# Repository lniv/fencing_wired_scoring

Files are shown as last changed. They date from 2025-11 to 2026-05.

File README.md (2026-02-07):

# A simple fencing scoring system

The aim is to make it simple, rather than efficient or super precise.\
Towards that, the hardware is a LED display with a matching controller from adafruit,
and circuitpython is used vs e.g. C. I tried to keep hardware to minimum, but pullup resisotrs appear necesssary for wired operation.

Note: foil only currently.

## Setup

### Display

#### Common to wired and wireless setups

These instructions assume a matrixportal-S3 is used as the display controller. There is nothing magical about it, but it is convenient.

- Install circuitpython on the matrixportal S3 : https://learn.adafruit.com/adafruit-matrixportal-s3/install-circuitpython
- Prep the portal and led display : https://learn.adafruit.com/adafruit-matrixportal-s3/prep-the-matrixportal
- Wire a buzzer between the A0 (battery connector) and ground.
- Copy [code.py](./code.py), [settings.toml](./settings.toml) and the various bmp files onto the circuitpython drive.

#### Additional display / connector setup for wired use:

I added the wireless option later, so e.g. the display legs or buzzer holder were integrated with parts that are necessary only for wired operation.

- Solder 2.2kohm (or similar) pullup resistors between the two weapon lines and 3V on the matriportalS3. These may not be necessary if you're using a different controller, in which case you should disable the pullup option ("HAVE_EXTERNAL_PULLUPS") in the settings.toml file.
- Print [display_connector.step](hardware/display_connector.step) and 2 or 3 of [display_leg](hardware/display_leg.step), and use a few M3x12 screws attach to display.
- Install and wire the six banana jacks.

### Wireless setups
- The two fencer boxes are described [here](./fencer_boxes/README.md).
- The display will create an AP with the ssid/password defined in the toml file - the default is ok for a single box.
- The three boxes can be powered on at any order, but if a fencer box doesn't find the AP, it will wait 5 sec before retrying, so if powered first you may have a 10 sec delay before hits can be registered.

## Usage
- Power display (and fencer boxes if used) via usb (typc-c, micro) connectors. The display likely needs ~ 10W.
- The display will setup up an AP (and operated in wireless mode) if the configuration file is deemed valid for wireless operation.
    - This can be overridden by holding the down button at startup.
- Audio can be enabled / disabled by holding the down button while a tip is pressed.
- Fence.

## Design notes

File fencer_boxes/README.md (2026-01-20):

# Fencer boxes used for a wireless setup

Obviously you'd need two of these. Oveall, they're a combination of a picow (RP2040 based) or pico2w (RP2350 based) with a custom front end.

## Hardware setup
* make a front end (duh). The schematics and layout for the front end are in [here](./front_end).
    * The front end is not tightly tied to the pico(2) pinout, though the code is. The current design uses a TSSOP opamp, which is a bit challenging to solder manually, but the other components were kept to 0805 mostly. The setup is simple enough that it could be built on a generic TSSOP adapter, but at 1$/board throush oshpark, why bother.
    * Wiring for a pico-w/pico2-w:
        * 8 pin header:
            * 1 : Not connected
            * 2 : ground
            * 3 : 3.3V
            * 4 : GP9 (tip sense line)
            * 5 : Not connected
            * 6 : GP10 (tip pullup line)
            * 7 : GP13 (lame drive)
            * 8 : GP26/A0 (lame sense)
        * 3 pin header:
            * 1 : A (lame)
            * 2 : B (weapon / tip)
            * 3 : C (ground / common)
* I typically CA glue them to the pico and wire the connections.
* Have a mechanical setup with the three banana jacks, wired to the front end
* power is via the micro usb connector - I use a small usb battery pack.

## Software setup
* Install circuitpython onto the board; for a pico2w, [https://circuitpython.org/board/raspberry_pi_pico2_w/]
* copy [code.py](./code.py) onto the board
* copy the [settings.toml from the parent folder](../settings.toml) file onto the board AND modify it to select either "left" or "right" side.

## TODO:
* Add step files for suitable hardware boxes
* Add BOM
* Replace opamp with a soic part.

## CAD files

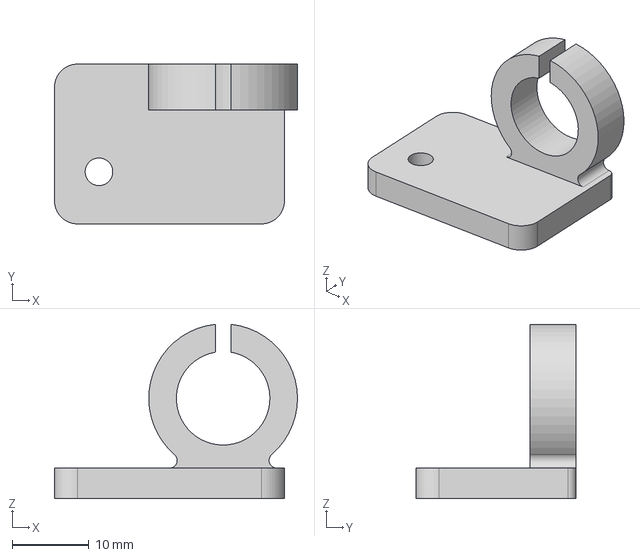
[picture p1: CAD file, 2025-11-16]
hardware/buzzer_holder.step
31.7 x 20.9 x 22.8 mm

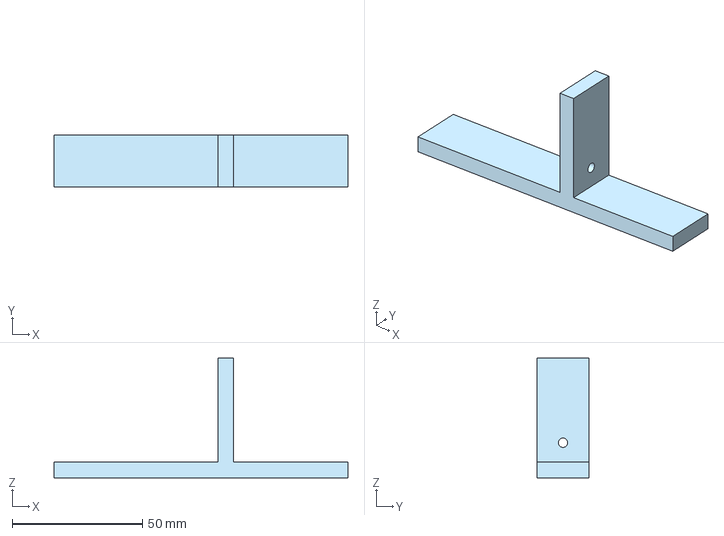
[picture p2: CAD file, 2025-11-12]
hardware/display_leg.step
113.0 x 20.0 x 46.0 mm

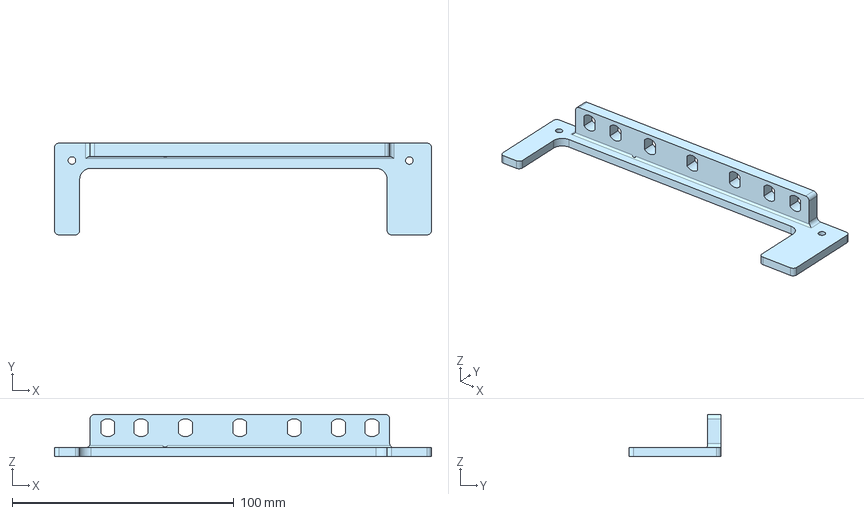
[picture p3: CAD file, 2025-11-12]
hardware/display_connector.step
169.9 x 41.3 x 19.0 mm

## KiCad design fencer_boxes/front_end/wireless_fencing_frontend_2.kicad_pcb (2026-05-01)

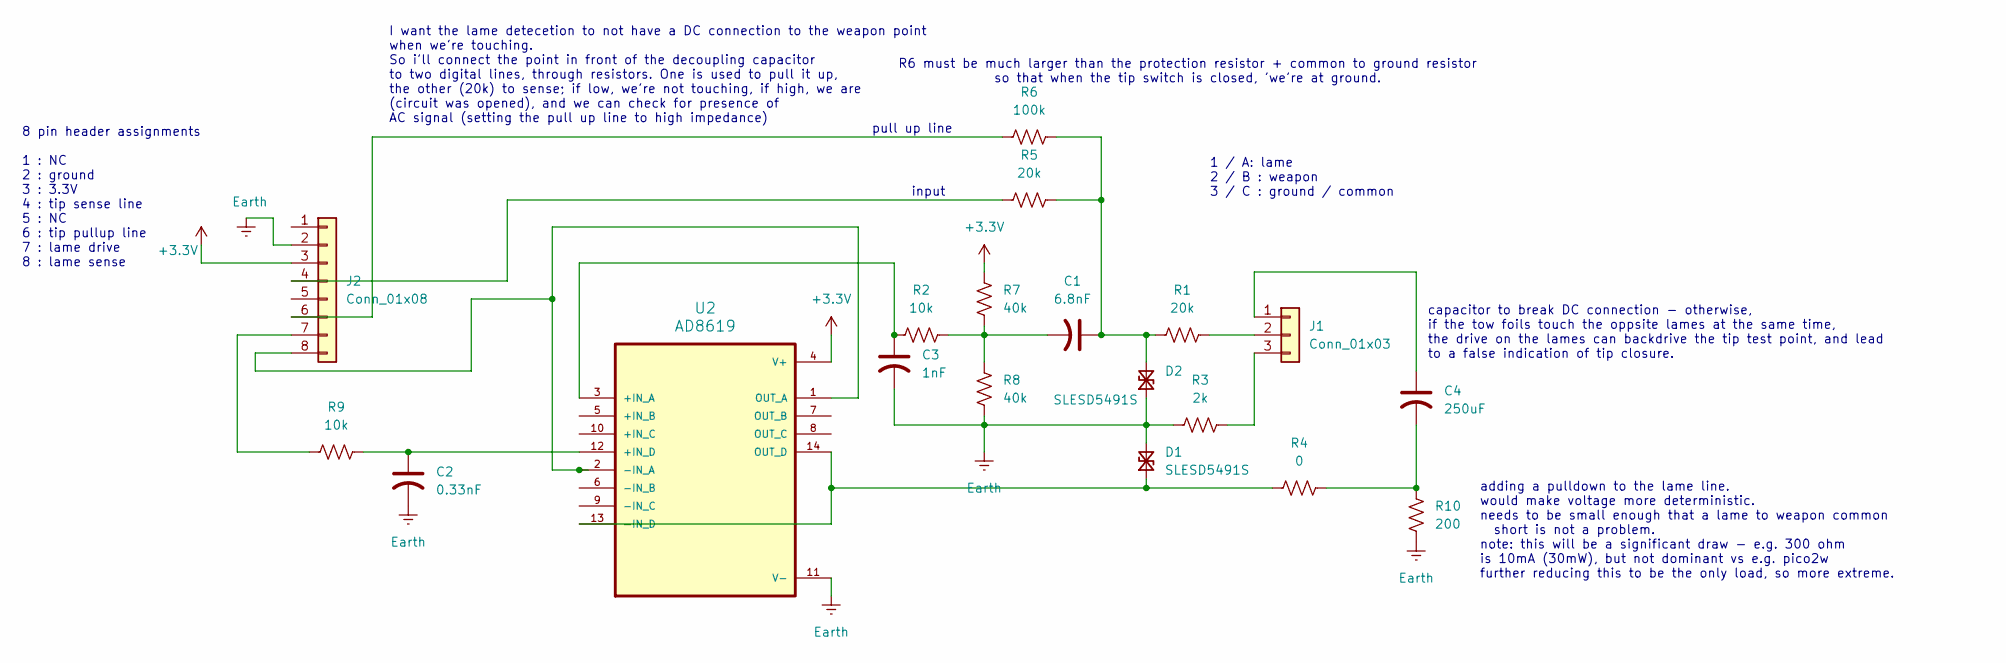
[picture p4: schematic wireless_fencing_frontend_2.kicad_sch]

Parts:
C1: 6.8nF; C_0805_2012Metric
C2: 0.33nF; C_0805_2012Metric
C3: 1nF; C_0805_2012Metric
C4: 250uF; C_0805_2012Metric
D1, D2: SLESD5491S; D_SOD-523
J1: Conn_01x03; PinHeader_1x03_P2.54mm_Vertical
J2: Conn_01x08; PinHeader_1x08_P2.54mm_Vertical
R1, R5: 20k; R_0805_2012Metric
R2, R9: 10k; R_0805_2012Metric
R3: 2k; R_0805_2012Metric
R4: 0; R_0805_2012Metric
R6: 100k; R_0805_2012Metric
R7, R8: 40k; R_0805_2012Metric
R10: 200; R_0805_2012Metric
U2: AD8619; SOP65P640X120-14N

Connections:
+3.3V: J2.3, R7.2, U2.4 (V+)
Earth: C2.2, C3.2, D1.2 (A2), D2.1 (A1), J2.2, R3.1, R8.1, R10.1, U2.11 (V-)
unnamed: C1.2, R2.1, R7.1, R8.2
unnamed: C4.2, R4.2, R10.2
unnamed: D1.1 (A1), R4.1, U2.13 (-IN_D), U2.14 (OUT_D)
unnamed: C1.1, D2.2 (A2), R1.1, R5.2, R6.1
unnamed: C4.1, J1.1
unnamed: J1.2, R1.2
unnamed: J1.3, R3.2
unnamed: J2.4, R5.1
unnamed: J2.6, R6.2
unnamed: J2.7, R9.1
unnamed: J2.8, U2.1 (OUT_A), U2.2 (-IN_A)
unnamed: C3.1, R2.2, U2.3 (+IN_A)
unnamed: C2.1, R9.2, U2.12 (+IN_D)

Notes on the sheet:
input
8 pin header assignments 1 : NC 2 : ground 3 : 3.3V 4 : tip sense line 5 : NC 6 : tip pullup line 7 : lame drive 8 : lame sense
R6 must be much larger than the protection resistor + common to ground resistor so that when the tip switch is closed, 'we're at ground.
pull up line
adding a pulldown to the lame line. would make voltage more deterministic. needs to be small enough that a lame to weapon common short is not a problem. note: this will be a significant draw - e.g. 300 ohm is 10mA (30mW), but not dominant vs e.g. pico2w further reducing this to be the only load, so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
capacitor to break DC connection - otherwise, if the tow foils touch the oppsite lames at the same time, the drive on the lames can backdrive the tip test point, and lead to a false indication of tip closure.
I want the lame detecetion to not have a DC connection to the weapon point when we're touching. So i'll connect the point in front of the decoupling capacitor to two digital lines, through resistors. One is used to pull it up, the other (20k) to sense; if low, we're not touching, if high, we are (c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
1 / A: lame 2 / B : weapon 3 / C : ground / common

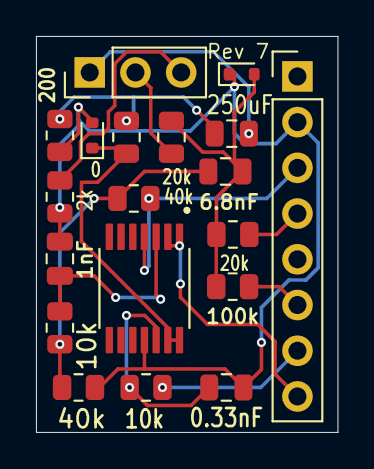
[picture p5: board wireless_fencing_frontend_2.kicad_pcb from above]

Board: 2 copper layers, 16.8 x 22.0 mm, 19 parts (0 on the bottom side), 15 nets.

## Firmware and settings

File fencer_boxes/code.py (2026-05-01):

"""
Code for a wireless fencer box.

need to be able to detect a switch closing, and whether we sense an AC signal (on the opponents lame), sending the results to a server/display.

Since we need the settings.toml for wireless, we'll use it as a general storage.
it will have multiple sections:
1. defines network ssid / password
2. defines which side we're on - you need to edit this, either right or left
3. has common items - e.g. the frequencies used on the lames, detection thresholds, lockout times...

while i could split the settings to multiple files, i decided i preferred a single file with sections.

NOTE: this was used originally with a pico2W i.e. a RP2350:
this required working around errata E9 - the pin latches up without an external
pulldown smaller than 8.2K !!
since the series protection resistor (which ground the pin through the tip) is 20k,
i chose to ground the pin in firmware instead.
"""

import board
from digitalio import DigitalInOut
import time
import analogbufio
import array
import math
import pwmio
import random

import wifi
import socketpool
from os import getenv
from ulab import numpy as np
from ulab.utils import from_uint16_buffer, spectrogram


# standardize on using monotonic_ns as integer, and have times in millisec.

print("Reading from settings.toml")
# before we do anything else, lets see that we have a sane definitions file.
# i could set loops etc here, but keeping names explicit makes the IDE's life easier.
settings = {}
for name in (
    "wifi_ssid",
    "wifi_password",
    "display_ip",
    "display_port",
    "fencer",
    "sampling_rate_Hz",
    "min_touch_msec",
    "sampling_end_to_min_touch_msec",
    "sampling_time_msec",
    "left_Hz",
    "right_Hz",
    "off_peak_offset_Hz",
    "min_valid_power",
    "send_touch_for_msec",
    "dormant_after_hit_msec",
    "message_repeat_min_msec",
    "message_repeat_max_msec",
):
    settings[name] = getenv(name)
    if settings[name] is None:
        raise RuntimeError(f"{name=} not found in settings.toml")

we_are = settings["fencer"]

# i'm going to optimize things to get a power of 2 adc reads
# since the ulab spectrogram requires it in any case.
sampling_rate = settings["sampling_rate_Hz"]
requested_sampling_time_sec = settings["sampling_time_msec"] * 1e-3
pow2_vec = np.array([2**n for n in range(16)])  # enough to ensure cover.
# NOTE: dropping the median filtering. if we decided to add it again,
# we'll need to add the extra 2*half median here.
array_length = int(
    pow2_vec[np.argmin(abs(pow2_vec - sampling_rate * requested_sampling_time_sec))]
)
sampling_time_sec = array_length / sampling_rate
print(
    f"{requested_sampling_time_sec=}, selecting closest 2**n so that {sampling_time_sec=}, {array_length=}"
)
# now find the best match for frequencies.
requested_right_freq = settings["right_Hz"]
requested_left_freq = settings["left_Hz"]
spectrogram_fs = np.linspace(0, sampling_rate / 2, int(array_length / 2 + 1))
right_freq_i = np.argmin(abs(spectrogram_fs - requested_right_freq))
left_freq_i = np.argmin(abs(spectrogram_fs - requested_left_freq))
# casting these since one will be use for a pwm call that takes an integer.
# it's true that these won't be exact, but 0.5 Hz offset seems acceptable.
right_freq = int(spectrogram_fs[right_freq_i])
left_freq = int(spectrogram_fs[left_freq_i])
print(f"Optimized to match spectrogram frequencies")
print(f"{requested_right_freq=} changed to {right_freq=}, {right_freq_i=}")
print(f"{requested_left_freq=} changed to {left_freq=}, {left_freq_i=}")


if we_are == "right":
    out_freq = right_freq
    target_freq = left_freq
    target_freq_i = left_freq_i
elif we_are == "left":
    out_freq = left_freq
    target_freq = right_freq
    target_freq_i = right_freq_i
else:
    raise RuntimeError(
        f"{settings['fencer']=} but we must be FENCER = RIGHT or FENCER = LEFT in settings.toml"
    )

requested_off_peak_offset = settings["off_peak_offset_Hz"]
# rather than look for best below/above indices, which may be not be exactly opposite,
# calculate an optimum delta
delta_i = np.argmin(abs(spectrogram_fs - requested_off_peak_offset))
below_peak_i = target_freq_i - delta_i
above_peak_i = target_freq_i + delta_i

off_peak_freqs = [spectrogram_fs[below_peak_i], spectrogram_fs[above_peak_i]]
print(
    f"Off peak {requested_off_peak_offset=} changed to {off_peak_freqs=}, {below_peak_i=}, {above_peak_i=}"
)


# we have a few floating point values, that due to the circuitpython toml limitations,
# must be loaded as ints. i might just change ot defining them otherwise...
# (i had more than one value, is swear...)
for name in ("min_valid_power",):
    settings[name] = float(settings[name])
    if settings[name] <= 0:
        raise ValueError(f"{name} must be a positive value.")

target_address = (settings["display_ip"], settings["display_port"])

# i'm using these with sleep later, and would prefer to not convert them each time.
message_repeat_min_sec = settings["message_repeat_min_msec"] / 1000
message_repeat_max_sec = settings["message_repeat_max_msec"] / 1000
dormant_after_hit_sec = settings["dormant_after_hit_msec"] / 1000
send_touch_for_ns = settings["send_touch_for_msec"] * 1e6
print(
    f"{dormant_after_hit_sec=}, {send_touch_for_ns=}, repeating every {message_repeat_min_sec:0.3f} to {message_repeat_max_sec:0.3f} sec"
)

print("settings.toml looks sane; proceeding.")

print(
    f"{we_are=}, output at {out_freq} Hz, looking for {target_freq} Hz, {off_peak_freqs=} Hz"
)

# hardware / pin definitions and setup

# connected to lame, through a lowpass filter, so we can do simple square wave.
# low pass will be at ~ 10kHz, so keep frequencies below that.
Lame_A_pin = board.GP13

# we have a resistor connected between the jack and each
# the pull up must be much larger than the protection resistor,
# since that's part of the line going to ground when the tip switch is closed.
# i.e. it won't "allow" it to be pulled to ground otherwise.
tip_B_pull_up_pin = DigitalInOut(board.GP10)  # 100kOhm
tip_B_sense_pin = DigitalInOut(board.GP9)  # 20 kOhm
# set both to high Z to begin.
# actually, i'm going to just have the pull up active
# (i could probably have omitted it and used the built in, but prefer more control.)
tip_B_pull_up_pin.switch_to_output(value=True)
tip_B_sense_pin.switch_to_input(pull=None)


# set up hardare (do this before betwork setup?)
pwm_out = pwmio.PWMOut(
    Lame_A_pin, duty_cycle=2**15, frequency=out_freq, variable_frequency=False
)
print(f"Playing pwm at {out_freq} on {Lame_A_pin}")


# future / TODO: heartbeat to display / server, get time sync from server?
detection_to_sampling_sec = (
    settings["min_touch_msec"] - settings["sampling_end_to_min_touch_msec"]
) * 1e-3 - sampling_time_sec
print(
    f"Will wait for {detection_to_sampling_sec} before sampling for {sampling_time_sec=}."
)

# # i'm going to run a median filter on the data, and do a linear fit subtraction.
# median_half_span = 2
# data_post_median_filt_indices = list(
#     range(median_half_span, array_length - median_half_span)
# )
# median_filtered_length = array_length - 2 * median_half_span
# t_vec = np.linspace(0, median_filtered_length / sampling_rate, median_filtered_length)
print(f"sampling for {sampling_time_sec=}, {sampling_rate=}, N={array_length}")
adc_read_buffer = array.array("H", [0x0000] * array_length)


########### finished setting up


def connect_to_wifi():
    """
    Low level connection to access point
    """
    ssid = settings["wifi_ssid"]
    passwd = settings["wifi_password"]
    print(f"Connecting to {ssid=}, {passwd=}")
    wifi.radio.connect(ssid, passwd)
    print("Connected to WiFi")


def reset_tip_state(ground_sec=0.001, delay_after_sec=0, repeats=1):
    """
    I'm getting repeat phantom touches, which i suspect are the rp2350 bug.
    the normal check does this momentarily, but we can afford to wait much longer after a touch
    (whether is_tip_depressed should as well, maybe)
    TODO: i should make this dependent on whether the board is an rp2350.
    """
    # work around for RP2350 errata E9 - the pin latches up without an external
    # pulldown smaller than 8.2K !!
    # since pulling it down to ground changes our protection, i'd rather do this.
    for _i in range(repeats):
        tip_B_sense_pin.switch_to_output(value=False)
        if ground_sec > 0:
            time.sleep(ground_sec)
        tip_B_sense_pin.switch_to_input(pull=None)
        if delay_after_sec > 0:
            time.sleep(delay_after_sec)


def is_tip_depressed(ground_sense_sec=0.003):
    """
    foil specific ; if we branch in the future, we'll define this based on weapon.
    NOTE: i've moved out any workaround for RP2350 latchup out of this.
    Args:
        ground_sense_sec: if positive, sleep with tip pulled down for this long [0.003]
    Returns:
        True if tip is found to be depressed/touching (circuit open).
    """
    return tip_B_sense_pin.value  # foil : circuit opens upon touch.


class FencerBox:
    """
    Core class looking for hits and sending messages when anything happens.
    """

    def __init__(self):
        self.sock = None
        self.t0_ns = time.monotonic_ns()
        self.connect_to_server()
        self.send_msg(f"{we_are},Just woke up,0,None,None", time.monotonic_ns())
        self.send_msg(
            f"{we_are},now in business - looking for hits,0,None,None", self.t0_ns, 0
        )
        self.run()

    def connect_to_server(self):
        """
        Connect to the display / server.
        Returns:
            a live socket
        """
        if isinstance(self.sock, socketpool.Socket):
            print("Socket existed, closing it before recreating.")
            self.sock.close()
        self.sock = pool.socket(pool.AF_INET, pool.SOCK_STREAM)
        self.sock.setsockopt(pool.IPPROTO_TCP, pool.TCP_NODELAY, 1)
        # sock.settimeout(1)  # very long, in general we should get something back fast.
        # this doesn't exist apparently?
        # sock.setsockopt(pool.SOL_SOCKET, pool.SO_KEEPALIVE, 1)
        print(f"Connecting to {target_address}")
        self.sock.connect(target_address)
        print("Connected.")

    def send_msg(self, msg: str, t_msg_ns: int, send_for_nanosec: int = 0) -> bool:
        """
        send a message to the display - which will have to parse it; simple string.
        Args:
            msg: send this to our display.
            t_msg_ns: when it happened, in nanosec.
            send_for_nanosec: will continue sending till t_msg + this expires, randomly.
        Returns:
            True if it managed to get through, False otherwise.
        """
        t_m1_ns = time.monotonic_ns()
        n_sent = 0
        try:
            # send once, then if we have time, repeat.
            while n_sent < 1 or time.monotonic_ns() - t_msg_ns < send_for_nanosec:
                t_now_ns = time.monotonic_ns()
                n_sent += 1
                # dropping spaces for easier processing, at the expense of humans.
                annotated_msg = (
                    f"{t_msg_ns};{t_now_ns - t_msg_ns};{n_sent};{msg}".encode("utf-8")
                )
                num_sent = self.sock.send(annotated_msg)
                if num_sent == 0:
                    raise OSError(128)  # not connected.
                t2_ns = time.monotonic_ns()
                # times are in nanosec, since it's native. we usually will deal with millisec for humans.
                print(
                    f"Took {(1e-6 * (t2_ns - t_m1_ns)):0.1f} msec to send {annotated_msg=}, N={num_sent}."
                )
                time.sleep(
                    random.uniform(
                        message_repeat_min_sec,
                        message_repeat_max_sec,
                    )
                )
                # # check if we got something back, if we did, we're done.
                # buf = bytearray(128)
                # print("trying to receive")
                # n_from_display = self.sock.recv_into(buf)
                # print(f"Got {n_from_display=}, {buf[:n_from_display]=}")
                # if n_from_display <= 0:
                #     print("Socket appears closed.")
                #     raise OSError(32)  # i know it's not exactly right, but seems closest.
                break

        except OSError as e:
            if e.args[0] in (
                118,  # 118 =EHOSTUNREACH
                128,  # 128 = ENOTCONN
                9,  # 9= EBADF
                32,  # 32 broken pipe
                116,  # ETIMEDOUT
            ):  # try to reconnect.
                print(f"Got {e=}, will try to reconnect.")
                try:
                    self.connect_to_server()
                except Exception as e:
                    try:
                        print(f"Failed to reconnect due to {e=}")
                        connect_to_wifi()
                        time.sleep(0.5)
                        self.connect_to_server()
                    except Exception as e:
                        print(f"Embarrassing, but we can't seen to connect due to {e=}")
            else:
                print(f"Got {e=}, not sure what to do about it.")
        except Exception as e:
            print(f"Error sending event: {e=}, {type(e)=}")
        return n_sent > 0

    def run(self):
        min_touch_nsec = settings["min_touch_msec"] * 1e6
        touch_i = 1
        while True:
            # this section till we evaluate the ADC buffer should be in a weapon dependent function.
            print(f"Waiting before {touch_i=}")
            # wait for touch, busy loop, doing nothing else to get maximal responsiveness.
            while not is_tip_depressed():
                pass
            t_now_ns = time.monotonic_ns()
            # drop the pullup, let the input float, so we don't rail things now.
            tip_B_pull_up_pin.switch_to_input(pull=None)
            # # maybe try grounding the source for some amount of time before looking for the ac signal?

            # wait some amount of time, then record vector (and a short one - it seemed best to wait more!)
            if detection_to_sampling_sec > 0:
                time.sleep(detection_to_sampling_sec)
            # now record.
            with analogbufio.BufferedIn(
                board.GP26, sample_rate=sampling_rate
            ) as adcbuf:
                adcbuf.readinto(adc_read_buffer)
            reset_tip_state(ground_sec=0.001, delay_after_sec=0, repeats=1)
            # now reactivate the pull up line.
            tip_B_pull_up_pin.switch_to_output(value=True)
            # now wait till min touch time has passed.
            print(f"since touch {(time.monotonic_ns() - t_now_ns)/1e6} msec")
            while time.monotonic_ns() - t_now_ns < min_touch_nsec:
                pass
            # check if the tip is still pressed.
            # (making it more foil specific for now, will need to refactor later for e.g. epee)
            if not is_tip_depressed():
                print(
                    "failed to find tip still pressed after checking validity, no touch."
                )
                continue
            # we have a valid touch, analyze data now.
            # calculate power at two frequencies
            # if this doesn't work (and it didn't do great before), will have to do pseudo -random,
            # or split the lame generation from the detection much harder (e.g. separate hardware)
            t_analysis_start_ns = time.monotonic_ns()
            data = from_uint16_buffer(
                adc_read_buffer
            )  # faster than np.array(adc_read_buffer) ?
            ss = spectrogram(data)
            pow = ss[target_freq_i]
            # use simple mean of the above and below peak frequencies.
            off_peak_pow = 0.5 * (ss[below_peak_i] + ss[above_peak_i])

            t_analysis_end_ns = time.monotonic_ns()
            print(f"Analysis too {t_analysis_end_ns - t_analysis_start_ns} nanosec")
            # moving the validity call to the display / control side.
            # i avoided it in the past to shorten cycle time, but timing it at 0.2 msec on an esp32-s3
            # in circuitpython, even with float conversions, so acceptable for now and makes debugging
            # easier.
            msg = f"{we_are},touched,{touch_i},{pow},{off_peak_pow}"
            # send, willing to repeat for some amount of time.
            self.send_msg(msg, t_now_ns, send_touch_for_ns)
            time_since_press_sec = (time.monotonic_ns() - t_now_ns) / 1e9
            # print(t_now_ns, time_since_press_sec, msg + f"; {pow=}")
            print(t_now_ns, time_since_press_sec, msg)
            # print(f"{time_since_press_sec=:0.4f} {dormant_after_hit_sec=:0.2f}")
            sleep_t = dormant_after_hit_sec - time_since_press_sec
            if sleep_t <= 0:
                print(f"{sleep_t=} <= 0; skipping sleep.")
            else:
                print(f"sleeping for {sleep_t:0.3f} sec")
                repeats = int(sleep_t / 0.01)
                reset_tip_state(ground_sec=0, delay_after_sec=0.01, repeats=repeats)
            post_announce_t_ns = time.monotonic_ns()
            msg = f"{we_are},Sent hit - slept - back in business,{touch_i},None,None"
            print(post_announce_t_ns, msg + "\n\n")
            self.send_msg(msg, post_announce_t_ns)
            touch_i += 1


######################### actually do something.
print(f"Initial connection to display AP")
while True:
    try:
        connect_to_wifi()
        break
    except ConnectionError as e:
        print(
            f"t = {(time.monotonic_ns() / 1e9):0.1f} sec: Failed to connect to display due to {e}, will wait 5 sec then retry."
        )
        time.sleep(5)

pool = socketpool.SocketPool(wifi.radio)
print("My MAC addr:", [hex(i) for i in wifi.radio.mac_address])
print(f"My IP address is {wifi.radio.ipv4_address}")
our_addr_s = str(wifi.radio.ipv4_address)
# now run.
FencerBox()

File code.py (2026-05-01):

print("en garde")
# so i don't have to look it up again (copied from https://en.wikipedia.org/wiki/Body_cord )
# The B pin is in the middle, the A pin is 1.5 cm to one side of B, and the C pin is 2 cm to the other side of B
# The A line is the "lamé" line, the B line is the "weapon" line, and the C line is the ground
# foil specific, we care about
# tip pressed : B \disconnected\ from C
# lame touching (and tip pressed!) : opposite A is connected to B (and disconnected from C - perhaps we can use that?)
# so, e.g. for right fencer:
# 1. right B is pullup, right C is ground ; check signal on B
# 2. C as VCC, left A is ground, check signal on B (if VCC : either tip is unpressed or lame is not touching, if ground, we're on target)

# hardware:
# display : Adafruit 64x32 matrix, specifically https://www.adafruit.com/product/2277
# controller : adafruit matrixportal S3 https://www.adafruit.com/product/5778
# buzzer : PS1240P02BT (4kHz - if using something else, may want to adjust buzzer frequency)
# banana jacks (for wired setup) : e.g. Cinch PN 108-0903-001
# 3d printed piece to hold banana jacks
# 3d printed piece(s) to hold the display upright
# 3d printed piece to holder the buzzer (mounts over the display adapter using a longer M3 screw)
# a few M3 screws - 12mm long for legs, banana jack mount, 16mm for clamping the buzzer over the latter.
# 2.2kOhm pull up resistors for the weapon lines (for wired setup).

# NOTE: currently this is foil specific ; i see no reason the flow can't be adapted to epee or sabre,
# but, 1. we may be running out of lines for the strip and 2. the (necesssary?) hardware pullups may
# make it weapon specifc, so that we'll need some additional hardware (switch, an i2c controlled matrix etc)
# to accommodate that.


from os import getenv
import time
import board
import select
from digitalio import DigitalInOut, Pull
import pwmio

import displayio
import rgbmatrix
import framebufferio

import socketpool
import wifi

# using one of the built in buttons to allow overriding mode.
# if using anything other than a matrixportal-S3, you may want to adjust.
mode_select_pin = board.BUTTON_DOWN
mode_select_button = DigitalInOut(mode_select_pin)
mode_select_button.switch_to_input(pull=Pull.UP)

settings = {}
# we have a few keys we must have defined.
required_keys = (
    "lockout_msec",
    "min_touch_msec",
    "buzzer_time_msec",
    "delay_before_display_reset_msec",
    "update_images_when_announcing",
    "default_audio_status",
)
for key in required_keys:
    settings[key] = getenv(key)
    if settings[key] is None:
        raise KeyError(f"{key} must be defined in settings.toml")
# for now, just set variables; i'll go to using settings directly later.
lockout_msec = settings["lockout_msec"]
min_touch_msec = settings["min_touch_msec"]


print(f"Checking if we're operating wirelessly.")
wireless_minimal_keys = (
    "wifi_ssid",
    "wifi_password",
    "display_ip",
    "display_port",
    "send_touch_for_msec",
    "min_valid_power",
    "min_valid_weighted_ratio",
)
for name in wireless_minimal_keys:
    settings[name] = getenv(name)
    if settings[name] is None:
        print(f"{name=} not found in settings.toml ; no wireless")
if set(settings.keys()).issuperset(wireless_minimal_keys):
    print("settings.toml compatible with wireless operation.")
    # allow overriding and going to wired mode if a button is held while initializing.
    if not mode_select_button.value:
        print("HOWEVER, overiding wireless valid config by button.")
        using_wireless = False
    else:
        using_wireless = True
else:
    using_wireless = False

if using_wireless:
    touch_sent_for_msec = settings["send_touch_for_msec"]
else:
    touch_sent_for_msec = 0

print(f"{using_wireless=}")
print(f"Using {lockout_msec=}, {min_touch_msec=} and {touch_sent_for_msec=}")


# TODO: organize this better.
right_A = DigitalInOut(board.D18)
right_B = DigitalInOut(board.D8)
right_C = DigitalInOut(board.A1)
left_A = DigitalInOut(board.A4)
left_B = DigitalInOut(board.A3)
left_C = DigitalInOut(board.A2)

# buzzer for end of action ; adjust frequency to hardwawre used.
buzzer = pwmio.PWMOut(board.A0, frequency=4000, duty_cycle=0)

all_pins = (right_A, right_B, right_C, left_A, left_B, left_C)
for i, pin in enumerate(all_pins):
    print(f"Setting pin {i} to input with no pullup")
    pin.switch_to_input(pull=None)


# below seems to work, but 1. ~ 4msec worst case, barely acceptable, and
# 2. the built in pullups really are too weak - even holding a wire from the oppsite lame to the tip registers.
# i'll try addding a real 1kohm pullup.
weapon_lines = {"right": right_B, "left": left_B}
lame_lines = {"right": right_A, "left": left_A}
common_lines = {"right": right_C, "left": left_C}

# weapon lines are pulled up (and normally grounded when the tip is not depressed, for foil.)
if not using_wireless:
    # if true, we'll disable the internal pullups and need external ones.
    # for my board, these is necessary.

    HAVE_EXTERNAL_PULLUPS = getenv("HAVE_EXTERNAL_PULLUPS")
    if HAVE_EXTERNAL_PULLUPS is None:
        raise ValueError(f"Must define HAVE_EXTERNAL_PULLUPS in settings.toml")
    for side in ("right", "left"):
        if HAVE_EXTERNAL_PULLUPS > 0:
            print(f"{side} relying on external pullups on the weapon line.")
            weapon_lines[side].switch_to_input(pull=None)
        else:
            print(f"{side} no external pullups, will try to use the internal ones.")
            weapon_lines[side].switch_to_input(pull=Pull.UP)


# yes, i should split the file etc, but this is mean more as a stream of conciousness development
# than neat and maintainable - it's pretty short so far, and i want to use it with kids.
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

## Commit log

2025-11-12 initial draft - print tip / valid status
    i.e. not timing etc, and hw not quite there.
    mostly for timing checks - on a matrix portal S3 i get ~4msec worst case.
    barely acceptable.
2025-11-12 Adding hw description and 2.2kOhm pullups.
    set a global to control behavior, e.g. for testing new setups
    before soldering pullups.
    The pullups do seem to make everything more reliable, at least
    as tested so far on short (i.e. only body cord) lines.
    [code.py]
2025-11-12 Adding buzzer code (but no buzzer yet)
    [code.py]
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2025-11-12 Adding hardware (3d printed parts) step files and mention in readme
    [display_connector.step, display_leg.step]
2025-11-13 move adding tiles to end of action
    added some debug "telemetry" for worst cycle since last action -
    This showed ~20 msec, which convinced me that we should try to improve it.
    Not surprisingly, adding the image to the tile was slow, so moving it helped.
    Also structured the loop so we don't check a side that's been announced (i.e.
    detected a touch) in the remaining time till lockout expires.
    I now see ~5 msec worst case, more typical 2 - 3 msec for the worst cycle.
2025-11-16 buzzer code cleanup and adjusting freq to hw used.
    [code.py]
2025-11-16 Adding step file for simple buzzer holder for a PS1240P02BT
    or anything else at 12.2mm diameter.
    attach over the banana jack holder that mounts to the display,
    using a longer M3 screw (16mm vs 12 mm)
    could merge it onto the banana plug holder, but chose to keep
    separate (and added later...)
    [buzzer_holder.step]
2025-11-17 fix reference and minimal contact time (for foil)
    note : since our cycle time is a few msec (typical ~ 2msec, worst case ~5msec),
    we don't actually conform to the +-1 msec contact time requirements.
    [code.py]
2025-11-23 fixed actually using lockout timing...
    at some point when i modified code it went unused.
    linting etc would have helped in this case.
    [code.py]
2025-12-30 Change timing of showing results to fencer
    1. buzzer start immediately on first hit detected (instead of after action
    ends)
    2. optional (defaults false, since it's slow atm), update display when the
    hit is detected, rather than waiting for the end of the action. This takes
    20 msec roughly, which is too slow imo during action.
    3. buzz an additional time after action is ended (i.e. up to lockout time +
    this extra time)
    4. Display the results for an additional time (2 sec) before restting.
    [code.py]
2025-12-30 removing frame wait when adding image to display stack
    left he instrumentation / prints that showed that it was the major
    time consumer.
    left the default of not displaying images immediately, even though
    these take ~ 3 - 4 msec extra (conpared to 0.15msec without) and this
    is probably ok, since i think i can improve things further.
2026-01-11 Adding wireless option
    dependent on setting.toml file, and (duh) fencer side boxes.
    those are still in a separate repo, and need to be combined.
2026-01-18 Adding description of wireless fencer boxes
    i.e. schematics and layout, code
    * i haven't yet marged the settings.toml file
    This was originally developed in a separate repo; i decided to lose the
    history and copied the files over.
    [wireless_fencing_frontend_2.kicad_pcb, wireless_fencing_frontend_2.kicad_sch]
2026-01-19 Combined settings.toml file and settled on time units
    also
    * can recover from the display being reset, recreating the connection to the AP
    * maybe fixed a small bug in checking the tip status (with the RP2350
    E9 bug)
    Not quite sure the acceptance of messages beyond the strict lockout (with lockout
    timing check used to validate them) is working correctly; I think i see a bogus hit on a next
    cycle in this case? may need to reset something / drop packets - maybe just read till we empty
    the buffer?
    [code.py]
2026-01-19 Fix looking for late messages beyond lockout time
    [code.py]
2026-01-19 drain socket before beginning next action
    solves the phantom hits coming in later
2026-01-19 When starting, will retry till connecting to AP
    rather than just fail and require reboot.
    this allows the display to be brought up after the fencer boxes
    [code.py]
2026-01-20 fix lame drive component values
    not sure these are final (higher f0 than i think is warranted),
    but seem to work ok and what i had was bad (i.e. different than
    intended and not working...)
    [wireless_fencing_frontend_2.kicad_pcb, wireless_fencing_frontend_2.kicad_sch]
2026-01-20 adjust valid power threshold
    working value for now; we'll see if it's too marginal, or if a
    different approach is needed for measuring the AC power.
2026-01-20 putting the lame drive resistor value in silkscreen
    [wireless_fencing_frontend_2.kicad_pcb]
2026-01-20 Adding front end to pico wiring assignments in readme
    [wireless_fencing_frontend_2.kicad_sch]
2026-01-20 front end tvs and resistor combination
    * Single SOD-523 footprint for TVS diodes
    * Changed from using 2x20kOhm in series to single 40kOhm.
    Initially was trying to minimize the number of different values, but resistors
    are like a cent a piece, even in pretty small quantities, and this saves soldering.
    [wireless_fencing_frontend_2.kicad_pcb, wireless_fencing_frontend_2.kicad_sch]
2026-01-24 checking touch validity should finish before min touch time
    timed the processing time, adjusted settings so that we can sample for a sane time,
    then process, and have some some spare time (which we spend in a busy loop) till
    the debounce window finishes.
2026-01-24 Shorten sleep times - can hit immediately, and display shorter time
    the previous times proved annoying when testing it.
    [code.py]
2026-01-26 image addition in real time controlled via settings.toml
    defaults to true, which is less of an issue for a wireless setup,
    partially cause i also am now dumping packets that arrived while
    processing a hit, so that i don't mark a it as 20 msec late.
    (hard to test manually if all this works ok, however)
    [code.py]
2026-01-26 fix bug where we accepeted new hit after announcing a side.
    this in effect reopened the lockout time, which is obviously wrong.
    [code.py]
2026-01-27 for wireless setups, inhibit buzzer if right A and shorted.
    checks each time we reset status, applies to next action.
    a bit of a kludge, but i have the jacks wired...
    [code.py]
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2026-02-07 silent / noisy controlled by same button used to select modes
    i.e. no longer by shorting A-C in wireless mode and nothing in wired.
    [code.py]
2026-02-07 fix audio status to be toggled by button press, not set.
    previous logic made sense when i was using a shorting wire.
    Also made the default controlled by the settings file.
    (with the note that it will get flipped at start if you're using
    the button to override wireless mode)
    [code.py]
2026-02-08 reverting to a lower threshold for a valid hit
    the higher one ended up being too high when i wasn't actually touching
    the lame - apparently that changed the coupling more than i thought.
2026-02-13 Adjusting parameters - together with a low pass filter added, work ok
    or barely acceptable, but maybe the best that can be done for now.
    I added a 11kohm / 1nF passive low pass - i forgot to put an anti alias
    in the design. Bumped up sampling to 80kHz, and shortened collection time
    (cause 5 msec for a 7/8kHz signal is plenty enough, i think)
    [code.py]
2026-02-22 major data processing changes
    * tip pullup is kept high other then when getting ac data
    * when waiting for hit, minimal busy loop just checking tip status
    * float tip, wait, collect AC data
    * reset tip status, then wait for minimal time to pass (if needed)
    * if hit is valid, then process data (i.e. outside of critical time)
    * data processing now has
    * a median filter (hard coded to a 5 long kernel)
    * subtracts a linear fit
    * changed threshold to a lower value - seems ok, but still more marginal
    than i'd like, so more changes may be coming.
    [code.py]
2026-02-22 going to higher frequencies - 11, 13 kHz
    i seem to get a bit better SNR here, and it's within same filters.
    may want to investigate going much higher (but keeping in mind an 83kHz
    adc limit if i want to use an esp32-s3 in the future)
2026-03-02 moving validity call to display
    * calculating power at a target and base freuqency, sending values
    to display. Processign is about 25 msec on the p2350, but it's the
    same on both sides, so not an issue there, and still much faster than
    human times.
    * call on validity made there, currently absolute + ratio limits
    * timed at 0.2-0.3msec, so accetable.
    * changed timing base for display / controller to be the time after a
    packet is received; timing showed even with a 10 msec timeout i got
    up to 150 msec there - yuck. May need to increase the send repeat time.
    [code.py]
2026-03-05 switch to using spectrogram rather than the Goertzel filters
    seems to work better in stationary testing, but i'm not sure how much
    margin i really have - i might need hardware changes to get stronger signal.
    Analysis may actually be faster - takes 1.4 or 3.4 msec (seems bistable)
    this uses a ulab pre compiled function...
    * since the ulab spectrogram (welch) requires power of 2 samples,
    adjust sampling time to match that.
    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
2026-03-05 remove commented out code
    * remains of debugging
    * the Goertzel algorithm and calls
    * the median filter
2026-03-06 redo validity criteria - off peak calc and use
    * rather than fixed base (non peak) frequency, specify a delta offset
    and use the mean value of the psd at this (approximate) offset above and
    below the peak frequency.
    * validity criteria changed so that the min peak/off peak ratio is multiplied
    by the (relative to the threshold) strength of the signal, so that a very prominent
    signal can be marginal and vice versa.
    * adjusted parameters - high enough min that i don't see accidental hits (by x1.5 -
    so still would like more margin).
    [code.py]
2026-03-07 Adding simple passive lowpass before adc buffer
    set to 10k, 1nF i.e. f0 16kHz ; used 11k, not critical.
    i've bodged this into the existing boards.
    [wireless_fencing_frontend_2.kicad_pcb, wireless_fencing_frontend_2.kicad_sch]
2026-03-15 lame drive changed from 20k to 2k
    just matching change in reality; not sure if it's important.
    [wireless_fencing_frontend_2.kicad_pcb, wireless_fencing_frontend_2.kicad_sch]
2026-03-29 Adding lame pulldown and common line to ground resistor
    so now the lame connection is
    1. on a voltage divider between the drive and ground, not floating.
    2. setting this to 100 ohm drive, 200 ohm to ground - so also much stronger than before.
    and the C (common) line is not tied directly to ground, but has a 2k resistor.
    Overall, this doesn't change the tip detection much, but should make the lame drive more
    resistant to the common line touching the lame (cause of e.g. sweaty skin). Before this
    changed it from floating to grounded, now it 1. does not connect it directly to ground,
    but only through a 2k resistor, and 2. the drive is much stronger and more deterministic,
    so this won't change t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
    [wireless_fencing_frontend_2.kicad_pcb, wireless_fencing_frontend_2.kicad_sch]
2026-03-30 Change to AC coupling of drive to lame
    i.e. add a capacitor on the line.
    with the recent addition of tying the lame drive to ground, if one
    foil touches the opposite lame, the moment the other touch happens -
    - even before the switch is actually depressed - the voltage at the
    pin can be back driven by the (opposite) lame and trigger a false touch.
    Braking the DC coupling solves it.
    [wireless_fencing_frontend_2.kicad_pcb, wireless_fencing_frontend_2.kicad_sch]
2026-04-13 Adjusting lame drive hardware for a stronger drive
    * reduce (well, eliminate) the inline resistance (i think not needed
    once we're capacitively coupled to the lame)
    * increase the capacitor from 100nF to 10uF.
    Both of these changes seem to do better when the lame is "shorted" to
    the common line; the current configs seem to do ok down to about 5kOhm
    of a short, but no lower - so a super sweaty fencer is still an issue,
    i think.
    [wireless_fencing_frontend_2.kicad_pcb, wireless_fencing_frontend_2.kicad_sch]
2026-04-20 two way comm - display acknowledges messages from boxes
    For the display it's a very minimal change - it replies to the sending
    address with a copy of what it received.
    On the fencer box side,
    * Once we receive a reply, we stop sending repeats.
    better behavior when two are sending in close proximity (before i
    relied on the random delays + repeeats, but i think it wasn't
    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
2026-04-23 NOT dumping packets during an action
    since we now will stop sending once we got an acknowledgment,
    it's better if we have a stale (relatively) packet rather than
    force a resend; the time limits i have a short enough that we might
    not get the resend through - which i think i've seen happen.
    note that we might want to set configs so we only send once,
    or drop adding the sending time to the allowed lockout time.
    Perhaps sending multiple times was a bad idea, and perhaps
    the receipt is not great (since it slows down the main loop)
    [code.py]
2026-05-01 Switch to TCP communication
    Seems to do better on normal use (i.e. actually timely manner of receiving
    hits), BUT, doesn't recover nicely if the display reboots (or likely if
    we drop the connection for other reasons)
    needs cleanup and refactoring.
    [code.py]
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2026-05-01 change lame capacitor to 250 uF
    seems to handle sweat etc better
    [wireless_fencing_frontend_2.kicad_pcb, wireless_fencing_frontend_2.kicad_sch]
